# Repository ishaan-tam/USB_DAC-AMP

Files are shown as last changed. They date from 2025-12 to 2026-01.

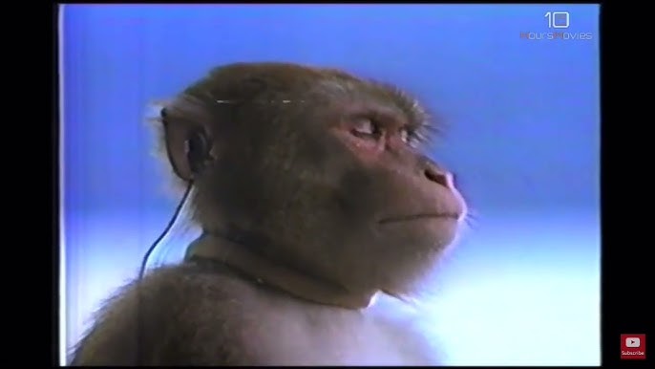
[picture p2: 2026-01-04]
Artwork/Monkey_listening_to_music.jpg

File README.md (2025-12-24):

# Pocket USB DAC Headphone Amp

# USB DAC + Baxandall Tone Control Headphone Amp  
**Checklist / Build Plan**

make sure that resistors are thin film, thich film resistors can introduce distortion
Chose electrolytic caps in the signal path as long as they are large enough, if chosing ceramic (sepecially in the signal path) chose type cog, otehrwise most ceramic caps will have piezoelectric effects and will introduce distortion 
bypass caps can be pretty much any type

For voltage ratings, useually go with double of what the expected DC voltage is
---

## Phase 0 — Lock the architecture
- [ ] Use **Phil’s USB headphone amplifier** as the base design
  - [ ] USB-C power + data
  - [ ] USB audio codec (PCM290x family)
  - [ ] DAC output buffer / reconstruction filter
  - [ ] Volume control stage
  - [ ] Output/current-drive stage to headphone jack
- [ ] Insert **TI Baxandall bass/treble tone control** as a line-level block
  - [ ] Signal flow:  
    **Phil DAC buffer → TI Baxandall tone → Phil volume → Phil output stage**
- [ ] Decide on **single master volume**
  - [ ] Use Phil’s volume control only
  - [ ] Bypass TI’s R1/R2 volume pots

---

## Phase 1 — KiCad schematic integration
- [ ] Create a **combined KiCad schematic**
  - [ ] Start from Phil’s schematic as the backbone
  - [ ] Add TI Baxandall tone block between Phil buffer output and Phil volume input
  - [ ] Keep TI input buffers initially (lower risk)
- [ ] **Bypass TI R1/R2 (volume pots)**
  - [ ] Remove R1/R2 from the TI tone schematic
  - [ ] Feed TI input buffer directly from the coupling cap
  - [ ] Add a DC bias path so the node does not float
  - [ ] (Optional) Add footprints / jumpers to re-enable pots if needed
- [ ] **Resolve virtual ground vs real ground**
  - [ ] Identify Phil’s analog reference / bias node (half-rail if single-supply)
  - [ ] Tie all TI “mid” nodes to Phil’s analog reference
  - [ ] Do NOT generate a separate TI virtual ground if Phil already provides one
- [ ] Perform a **sanity check**
  - [ ] Verify signal levels between stages
  - [ ] Ensure tone boost will not clip internal op-amps
  - [ ] Ensure compatibility with Phil’s volume stage input impedance

---

## Phase 2 — BOM & sourcing
- [ ] Create a **BOM from the combined schematic**
  - [ ] ICs (codec, op-amps, regulators)
  - [ ] Precision resistors where required
  - [ ] Capacitors (type + voltage rating)
  - [ ] Dual-gang pots for bass/treble
  - [ ] USB-C connector, headphone jack
  - [ ] Protection parts (ESD diodes, fuses, ferrites)
- [ ] Align BOM with **JLCPCB / LCSC availability**
  - [ ] Decide which ICs are hand-soldered
  - [ ] Mark which passives are PCBA-assembled
- [ ] Order parts
  - [ ] Order extras for iteration (pots, op-amps, passives)

---

## Phase 3 — Build & test
- [ ] Bring-up in stages
  - [ ] Test Phil’s base circuit (USB enumeration + clean audio)
  - [ ] Enable TI Baxandall tone block
  - [ ] Verify flat response at center
  - [ ] Verify bass/treble behavior
- [ ] Full system test
  - [ ] Verify volume control behavior
  - [ ] Test with headphones
  - [ ] Listen for noise, clipping, oscillation

---

## Phase 4 — Rev A refinement
- [ ] Adjust Baxandall network for **subtle** tone range if needed
- [ ] Improve decoupling/layout if noise or instability appears
- [ ] Finalize schematic and prepare for PCB layout / PCBA

A compact, USB-powered headphone amplifier built around a **class-compliant USB audio codec**, with an **analog signal path**, **physical volume control**, and room to add **Baxandall bass/treble tone shaping** in later revisions.

This project prioritizes:
- **Fun, hands-on analog audio**
- **Simple, driverless USB DAC operation**
- **Incremental development** (breadboard → PCB Rev A → Rev B tone control)

Not meant to be “audiophile-perfect,” but absolutely meant to be **good enough that I actually want to use it**.

---

## Project Status

- **Current phase:** Rev 0 — Breadboard prototype
- **Goal of Rev 0:**  
  - USB device enumerates as an audio output  
  - Audio plays cleanly through headphones  
  - Volume control works  
- **Future phases:**  
  - Rev A PCB (compact, USB-C, integrated headphone stage)  
  - Rev B (add Baxandall bass/treble tone control)

---

## High-Level Architecture

USB-C
│
├─ USB 2.0 D+/D−
│
PCM2906C USB Audio Codec
│
├─ DAC L/R (line-level)
│
Buffer + Reconstruction Filter
│
(Rev B) Baxandall Tone Control (Bass / Treble)
│
Volume Control
│
Headphone Output Stage
│
3.5 mm Headphone Jack

---

## Key Design Decisions

### USB Audio Codec
- **TI PCM2906C**
  - USB Audio Class 1 (driverless)
  - Plug-and-play on **Windows, macOS, Linux**
  - Likely works on **USB-C iPhones** (with power constraints)
  - Chosen over older PCM2900 due to **availability / active status**

S/PDIF pins are **not used** in this project.

---

### Power Strategy
- **Rev 0 (breadboard):**  
  - USB 5 V only  
  - No boost converter  
- **Rev A (PCB):**  
  - USB 5 V → boost → clean analog rail (12–15 V)  
  - Boost is for **headroom**, not “audio amplification”

---

### Analog Audio Philosophy
- Keep the **DAC isolated** from headphone loads
- Use **buffers** and **volume control** before the output stage
- Tone control is **optional and playful**, not surgical EQ
- If “serious EQ” is needed → do it digitally in software

---

### Tone Control Plan
- **Baxandall bass/treble** (2 knobs)
  - Musical, forgiving
  - Simple, stable, well-understood
- Will be added in **Rev B**
- Rev A PCB should reserve insertion points for it

---

## Breadboard Prototype (Rev 0)

### What Rev 0 Includes
- PCM2906C wired per TI **Typical Application Circuit**
- 12 MHz crystal + required decoupling
- USB-C input (USB 2.0 only)
- Line-level L/R output
- External headphone amp module **or** simple buffer + volume pot
- Goal: **“I hear sound and can control volume”**

### What Rev 0 Intentionally Avoids
- Boost converters
- Parallel op-amps
- Tone controls
- EMI optimization
- Fancy layouts

Rev 0 is about **function, not polish**.

---

## Headphone Output (Rev 0 Approach)

For breadboarding, the headphone stage is intentionally simplified:

### Options
1. **External headphone amp module**
   - Accepts line-level L/R
   - Powered from 5 V
   - Drives headphones safely
2. **DIY buffer + volume + output stage**
   - Unity-gain buffer
   - Passive volume pot
   - Headphone-capable driver

Modules are preferred for Rev 0 to avoid stability issues on a breadboard.

---

## Compatibility Expectations

- **Windows:** ✅ Plug-and-play
- **macOS / Linux:** ✅ Plug-and-play
- **USB-C iPhone:** ⚠️ Likely works, power-dependent
- **Lightning iPhone:** ⚠️ Requires camera adapter

---

## Repository Structure

pocket-usb-dac-amp/
├─ README.md
├─ docs/
│ ├─ requirements.md
│ ├─ architecture.md
│ ├─ bringup-notes.md
│ └─ images/
├─ hardware/
│ ├─ rev0_breadboard/
│ │ ├─ wiring/
│ │ └─ bom/
│ │ └─ bom_rev0.xlsx
│ ├─ revA_pcb/
│ │ ├─ kicad/
│ │ ├─ outputs/
│ │ └─ bom/
│ └─ revB_tonecontrol/
├─ tools/
│ └─ bom/
└─ CHANGELOG.md

---

## BOM Management

- BOMs are maintained in **Excel**
- Each revision has its own BOM:
  - `bom_rev0.xlsx`
  - `bom_revA.xlsx`
- BOM includes:
  - Manufacturer + MPN
  - Supplier + SKU
  - Unit cost
  - Alternates
  - Notes (DNP, experimental, etc.)

KiCad-exported CSVs are treated as **derived artifacts**, not the source of truth.

---

## Development Philosophy

- Build **one working version at a time**
- Breadboard first, PCB later
- Prefer **known-good reference circuits**
- Avoid “clever” designs that increase debug time
- Leave room for iteration and learning

---

## Non-Goals (Important)

- Not chasing ultra-low THD numbers
- Not competing with commercial DACs
- Not building a DSP playground
- Not optimizing for mass production

This is a **learning + enjoyment project**, not a product launch.

---

## Next Immediate Steps

1. Finish Rev 0 breadboard wiring
2. Confirm USB enumeration + audio playback
3. Document bring-up issues and fixes
4. Decide:
   - integrated output stage vs module
5. Begin Rev A schematic capture

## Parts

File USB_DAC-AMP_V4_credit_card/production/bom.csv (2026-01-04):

Designator | Footprint | Quantity | Value | LCSC Part #
C1, C11, C14, C19, C2, C20, C21, C23 | 0603 | 8 | 1u | C1592
C10, C12, C13, C15, C16, C28, C31, C4, C40, C43, C9 | 0603 | 11 | 30p | C1658
C17, C18, C22, C3, C5, C6, C8 | 0603 | 7 | 10u | C1035
C24, C25, C33, C34, C36, C37, C45 | 0603 | 7 | 100n | C1590
C26, C38 | CP_Elec_10x10.5 | 2 | 1000u | C3359
C27, C29, C32, C35, C39, C41, C44, C7 | CP_Elec_6.3x7.7 | 8 | 100u | C3339
C30, C42 | 0603 | 2 | 2.2n | C1028
D1, D5 | D_SMA | 2 | SS14 | C2480
D2 | 0603 | 1 | LED | C84265
D3, D4, D6, D7 | 0603 | 4 | D_TVS | C316055
F1 | 0603 | 1 | Polyfuse - 750mA | C20787
FB1, FB2, FB3, FB4, FB5 | 0603 | 5 | 120R | C12391
J1 | USB_C_Receptacle_GCT_USB4105-xx-A_16P_TopMnt_Horizontal | 1 | USB_C_Receptacle | C5184243
J2 | SJ-3524-SMT | 1 | SJ-3524-SMT
L1 | 0805 | 1 | 10u | C223269
R1 | 0603 | 1 | 20 | C136969
R10, R2 | 0603 | 2 | 1M | C326730
R11, R12, R24, R35, R5, R6 | 0603 | 6 | 5.1K | C122969
R13, R14, R15, R20, R25, R28, R29, R30, R32, R36, R39, R8 | 0603 | 12 | 22K | C217885
R16, R22, R23, R26, R33, R34, R37, R4, R40 | 0603 | 9 | 1.5K | C193681
R17, R18 | 0603 | 2 | 22 | C217888
R19, R27, R31, R38, R9 | 0603 | 5 | 1 | C412388
R21 | TRIM_PTN092-H20115K1A | 1 | PTN092-H20115K1A
R3 | 0603 | 1 | 240K | C217899
R7 | 0603 | 1 | 84.5K | C705797
TP1 | TestPoint_Pad_1.0x1.0mm | 1 | +5V
TP11 | TestPoint_Pad_1.0x1.0mm | 1 | buffer2_r
TP12 | TestPoint_Pad_1.0x1.0mm | 1 | buffer2_l
TP13 | TestPoint_Pad_1.0x1.0mm | 1 | in_l
TP14 | TestPoint_Pad_1.0x1.0mm | 1 | in_r
TP15 | TestPoint_Pad_1.0x1.0mm | 1 | buffer1_l
TP16 | TestPoint_Pad_1.0x1.0mm | 1 | buffer1_r
TP2 | TestPoint_Pad_1.0x1.0mm | 1 | +16V
TP3 | TestPoint_Pad_1.0x1.0mm | 1 | +15VA
TP4 | TestPoint_Pad_1.0x1.0mm | 1 | +3.7V
TP5 | TestPoint_Pad_1.0x1.0mm | 1 | U1_VCCI
TP6 | TestPoint_Pad_1.0x1.0mm | 1 | VBL
TP7 | TestPoint_Pad_1.0x1.0mm | 1 | VREF
TP8 | TestPoint_Pad_1.0x1.0mm | 1 | VBR
U1 | SOT-23-5 | 1 | TPS61040DBV | C7722
U10, U11, U5, U6, U7, U8, U9 | SOIC-8_3.9x4.9mm_P1.27mm | 7 | NE5532 | C7426
U2, U3 | SOT-23-5 | 2 | SPX3819M5-L | C9056
U4 | SSOP-28_5.3x10.2mm_P0.65mm | 1 | PCM2900C | C180425
Y1 | Crystal_SMD_3225-4Pin_3.2x2.5mm | 1 | 12 MHz Crystal | C9002

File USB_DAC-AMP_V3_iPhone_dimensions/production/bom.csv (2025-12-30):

Designator | Footprint | Quantity | Value | LCSC Part #
C1, C10, C11, C12, C13, C19, C9 | 0603 | 7 | 10u
C14, C15, C35, C45 | CP_EIA-7343-43_Kemet-X_HandSolder | 4 | 1000u
C16, C17, C18, C20, C21, C22, C7, C8 | 0603 | 8 | 1u
C2, C23, C24, C3, C33, C36, C4, C43, C46, C5, C6 | 0603 | 11 | 30p
C25, C27, C30, C31, C40, C41 | CP_EIA-7343-43_Kemet-X_HandSolder | 6 | 100u
C26, C28, C32, C34, C38, C42, C44, C47 | 0603 | 8 | 100n
C29, C39 | 0603 | 2 | 2.2n
C37 | CP_EIA-7343-15_Kemet-W | 1 | 100u
D1, D6, D7 | 0603 | 3 | D_TVS
D2 | 0603 | 1 | 0603ESDA-18N
D3 | 0603 | 1 | LED
D4, D5 | D_SMA | 2 | SS14
F1 | 0603 | 1 | Polyfuse - 750mA
FB1, FB2, FB3, FB4, FB5 | 0603 | 5 | 120R
J1 | USB_C_Receptacle_GCT_USB4105-xx-A_16P_TopMnt_Horizontal | 1 | USB_C_Receptacle
J2 | SJ-3524-SMT | 1 | SJ-3524-SMT
L1 | 0805 | 1 | 10u
R1, R2, R30, R40 | 0603 | 4 | 5.1K
R10 | 0603 | 1 | 240K
R11, R23, R24, R25, R29, R34, R39, R7, R8, R9 | 0603 | 10 | 22K
R12 | 0603 | 1 | 20
R13, R16, R20, R21, R26, R27, R28, R33, R35, R36, R38, R43 | 0603 | 12 | 1.5K
R14, R15 | 0603 | 2 | 22
R17, R31, R32, R41, R42 | 0603 | 5 | 1
R22, R5 | 0603 | 2 | 1M
R3 | TRIM_PTN092-H20115K1A | 1 | PTN092-H20115K1A
R6 | 0603 | 1 | 84.5K
TP1 | TestPoint_Pad_1.0x1.0mm | 1 | +5V
TP2 | TestPoint_Pad_1.0x1.0mm | 1 | +16V
TP3 | TestPoint_Pad_1.0x1.0mm | 1 | +3.7V
TP4 | TestPoint_Pad_1.0x1.0mm | 1 | +15VA
TP5 | TestPoint_Pad_1.0x1.0mm | 1 | VREF
TP6 | TestPoint_Pad_1.0x1.0mm | 1 | U1_VCCI
TP7 | TestPoint_Pad_1.0x1.0mm | 1 | VBL
TP8 | TestPoint_Pad_1.0x1.0mm | 1 | VBR
U1 | SSOP-28_5.3x10.2mm_P0.65mm | 1 | PCM2900C
U10, U11, U5, U6, U7, U8, U9 | SOIC-8_5.3x5.3mm_P1.27mm | 7 | NE5532
U2 | SOT-23-5 | 1 | TPS61040DBV
U3, U4 | SOT-23-5 | 2 | SPX3819M5-L
Y3 | Crystal_SMD_3225-4Pin_3.2x2.5mm | 1 | 12 MHz Crystal

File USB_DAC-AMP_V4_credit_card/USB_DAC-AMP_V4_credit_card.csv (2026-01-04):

Value | LCSC | Reference | Footprint | Qty
1u | C1592 | C1,C2,C11,C14,C19,C20,C21,C23 | Capacitor_SMD:C_0603_1608Metric | 8
10u | C1035 | C3,C5,C6,C8,C17,C18,C22 | Capacitor_SMD:C_0603_1608Metric | 7
30p | C1658 | C4,C9,C10,C12,C13,C15,C16,C28,C31,C40,C43 | Capacitor_SMD:C_0603_1608Metric | 11
100n | C1590 | C24,C25,C33,C34,C36,C37,C45 | Capacitor_SMD:C_0603_1608Metric | 7
2.2n | C1028 | C30,C42 | Capacitor_SMD:C_0603_1608Metric | 2
1000u | C3359 | C26,C38 | Capacitor_SMD:CP_Elec_10x10.5 | 2
100u | C3339 | C7,C27,C29,C32,C35,C39,C41,C44 | Capacitor_SMD:CP_Elec_6.3x7.7 | 8
USB_C_Receptacle | C5184243 | J1 | Connector_USB:USB_C_Receptacle_GCT_USB4105-xx-A_16P_TopMnt_Horizontal | 1
12 MHz Crystal | C9002 | Y1 | Crystal:Crystal_SMD_3225-4Pin_3.2x2.5mm | 1
D_TVS | C316055 | D3,D4,D6,D7 | Diode_SMD:D_0603_1608Metric | 4
SS14 | C2480 | D1,D5 | Diode_SMD:D_SMA | 2
Polyfuse - 750mA | C20787 | F1 | Fuse:Fuse_0603_1608Metric | 1
SJ-3524-SMT |  | J2 | Imported_footprints:SJ-3524-SMT | 1
PTN092-H20115K1A |  | R21 | Imported_footprints:TRIM_PTN092-H20115K1A | 1
10u | C223269 | L1 | Inductor_SMD:L_0805_2012Metric | 1
LED | C84265 | D2 | LED_SMD:LED_0603_1608Metric | 1
MountingHole |  | H1,H2,H3,H4 | MountingHole:MountingHole_3.5mm | 4
NE5532 | C7426 | U5,U6,U7,U8,U9,U10,U11 | Package_SO:SOIC-8_3.9x4.9mm_P1.27mm | 7
PCM2900C | C180425 | U4 | Package_SO:SSOP-28_5.3x10.2mm_P0.65mm | 1
TPS61040DBV | C7722 | U1 | Package_TO_SOT_SMD:SOT-23-5 | 1
SPX3819M5-L | C9056 | U2,U3 | Package_TO_SOT_SMD:SOT-23-5 | 2
120R | C12391 | FB1,FB2,FB3,FB4,FB5 | Resistor_SMD:R_0603_1608Metric | 5
20 | C136969 | R1 | Resistor_SMD:R_0603_1608Metric | 1
1M | C326730 | R2,R10 | Resistor_SMD:R_0603_1608Metric | 2
240K | C217899 | R3 | Resistor_SMD:R_0603_1608Metric | 1
1.5K | C193681 | R4,R16,R22,R23,R26,R33,R34,R37,R40 | Resistor_SMD:R_0603_1608Metric | 9
5.1K | C122969 | R5,R6,R11,R12,R24,R35 | Resistor_SMD:R_0603_1608Metric | 6
84.5K | C705797 | R7 | Resistor_SMD:R_0603_1608Metric | 1
22K | C217885 | R8,R13,R14,R15,R20,R25,R28,R29,R30,R32,R36,R39 | Resistor_SMD:R_0603_1608Metric | 12
1 | C412388 | R9,R19,R27,R31,R38 | Resistor_SMD:R_0603_1608Metric | 5
22 | C217888 | R17,R18 | Resistor_SMD:R_0603_1608Metric | 2
+5V |  | TP1 | TestPoint:TestPoint_Pad_1.0x1.0mm | 1
+16V |  | TP2 | TestPoint:TestPoint_Pad_1.0x1.0mm | 1
+15VA |  | TP3 | TestPoint:TestPoint_Pad_1.0x1.0mm | 1
+3.7V |  | TP4 | TestPoint:TestPoint_Pad_1.0x1.0mm | 1
U1_VCCI |  | TP5 | TestPoint:TestPoint_Pad_1.0x1.0mm | 1
VBL |  | TP6 | TestPoint:TestPoint_Pad_1.0x1.0mm | 1
VREF |  | TP7 | TestPoint:TestPoint_Pad_1.0x1.0mm | 1
VBR |  | TP8 | TestPoint:TestPoint_Pad_1.0x1.0mm | 1
buffer2_r |  | TP11 | TestPoint:TestPoint_Pad_1.0x1.0mm | 1
buffer2_l |  | TP12 | TestPoint:TestPoint_Pad_1.0x1.0mm | 1
in_l |  | TP13 | TestPoint:TestPoint_Pad_1.0x1.0mm | 1
in_r |  | TP14 | TestPoint:TestPoint_Pad_1.0x1.0mm | 1
buffer1_l |  | TP15 | TestPoint:TestPoint_Pad_1.0x1.0mm | 1
buffer1_r |  | TP16 | TestPoint:TestPoint_Pad_1.0x1.0mm | 1

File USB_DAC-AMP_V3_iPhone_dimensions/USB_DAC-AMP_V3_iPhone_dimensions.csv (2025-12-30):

Value | LCSC | Reference | Footprint | Qty
10u | C1035 | C1,C9,C10,C11,C12,C13,C19 | Capacitor_SMD:C_0603_1608Metric_Pad1.08x0.95mm_HandSolder | 7
30p | C1658 | C2,C3,C4,C5,C6,C23,C24,C33,C36,C43,C46 | Capacitor_SMD:C_0603_1608Metric_Pad1.08x0.95mm_HandSolder | 11
1u | C1592 | C7,C8,C16,C17,C18,C20,C21,C22 | Capacitor_SMD:C_0603_1608Metric_Pad1.08x0.95mm_HandSolder | 8
1000u | C696799 | C14,C15,C35,C45 | Capacitor_Tantalum_SMD:CP_EIA-7343-43_Kemet-X_HandSolder | 4
100u | C132558 | C25,C27,C30,C31,C40,C41 | Capacitor_Tantalum_SMD:CP_EIA-7343-43_Kemet-X_HandSolder | 6
100n | C1590 | C26,C28,C32,C34,C38,C42,C44,C47 | Capacitor_SMD:C_0603_1608Metric_Pad1.08x0.95mm_HandSolder | 8
2.2n | C1028 | C29,C39 | Capacitor_SMD:C_0603_1608Metric_Pad1.08x0.95mm_HandSolder | 2
100u | C1002 | C37 | Capacitor_Tantalum_SMD:CP_EIA-7343-15_Kemet-W | 1
D_TVS | C316055 | D1,D2,D6,D7 | Diode_SMD:D_0603_1608Metric_Pad1.05x0.95mm_HandSolder | 4
LED | C2288 | D3 | LED_SMD:LED_0603_1608Metric_Pad1.05x0.95mm_HandSolder | 1
SS14 | C2480 | D4,D5 | Diode_SMD:D_SMA | 2
Polyfuse - 750mA | C20787 | F1 | Fuse:Fuse_0603_1608Metric_Pad1.05x0.95mm_HandSolder | 1
120R | C12391 | FB1,FB2,FB3,FB4,FB5 | Resistor_SMD:R_0603_1608Metric_Pad0.98x0.95mm_HandSolder | 5
MountingHole |  | H1,H2,H3,H4 | MountingHole:MountingHole_3.5mm | 4
USB_C_Receptacle | C5184243 | J1 | Connector_USB:USB_C_Receptacle_GCT_USB4105-xx-A_16P_TopMnt_Horizontal | 1
SJ-3524-SMT |  | J2 | Imported_footprints:SJ-3524-SMT | 1
10u | C223269 | L1 | Inductor_SMD:L_0805_2012Metric_Pad1.05x1.20mm_HandSolder | 1
5.1K | C122969 | R1,R2,R30,R40 | Resistor_SMD:R_0603_1608Metric_Pad0.98x0.95mm_HandSolder | 4
PTN092-H20115K1A |  | R3 | Imported_footprints:TRIM_PTN092-H20115K1A | 1
1M | C705797 | R5,R22 | Resistor_SMD:R_0603_1608Metric_Pad0.98x0.95mm_HandSolder | 2
84.5K |  | R6 | Resistor_SMD:R_0603_1608Metric_Pad0.98x0.95mm_HandSolder | 1
22K |  | R7,R8,R9,R11,R23,R24,R25,R29,R34,R39 | Resistor_SMD:R_0603_1608Metric_Pad0.98x0.95mm_HandSolder | 10
240K |  | R10 | Resistor_SMD:R_0603_1608Metric_Pad0.98x0.95mm_HandSolder | 1
20 |  | R12 | Resistor_SMD:R_0603_1608Metric_Pad0.98x0.95mm_HandSolder | 1
1.5K |  | R13,R16,R26,R27,R28,R33,R35,R36,R38,R43 | Resistor_SMD:R_0603_1608Metric_Pad0.98x0.95mm_HandSolder | 10
22 |  | R14,R15 | Resistor_SMD:R_0603_1608Metric_Pad0.98x0.95mm_HandSolder | 2
1 |  | R17,R31,R32,R41,R42 | Resistor_SMD:R_0603_1608Metric_Pad0.98x0.95mm_HandSolder | 5
1.5k |  | R20,R21 | Resistor_SMD:R_0603_1608Metric_Pad0.98x0.95mm_HandSolder | 2
+5V |  | TP1 | TestPoint:TestPoint_Pad_1.0x1.0mm | 1
+16V |  | TP2 | TestPoint:TestPoint_Pad_1.0x1.0mm | 1
+3.7V |  | TP3 | TestPoint:TestPoint_Pad_1.0x1.0mm | 1
+15VA |  | TP4 | TestPoint:TestPoint_Pad_1.0x1.0mm | 1
VREF |  | TP5 | TestPoint:TestPoint_Pad_1.0x1.0mm | 1
U1_VCCI |  | TP6 | TestPoint:TestPoint_Pad_1.0x1.0mm | 1
VBL |  | TP7 | TestPoint:TestPoint_Pad_1.0x1.0mm | 1
VBR |  | TP8 | TestPoint:TestPoint_Pad_1.0x1.0mm | 1
PCM2900C | C180425 | U1 | Package_SO:SSOP-28_5.3x10.2mm_P0.65mm | 1
TPS61040DBV | C7722 | U2 | Package_TO_SOT_SMD:SOT-23-5 | 1
SPX3819M5-L | C9056 | U3,U4 | Package_TO_SOT_SMD:SOT-23-5 | 2
NE5532 | C7426 | U5,U6,U7,U8,U9,U10,U11 | Package_SO:SOIC-8_5.3x5.3mm_P1.27mm | 7
12 MHz Crystal | C9002 | Y3 | Crystal:Crystal_SMD_3225-4Pin_3.2x2.5mm | 1

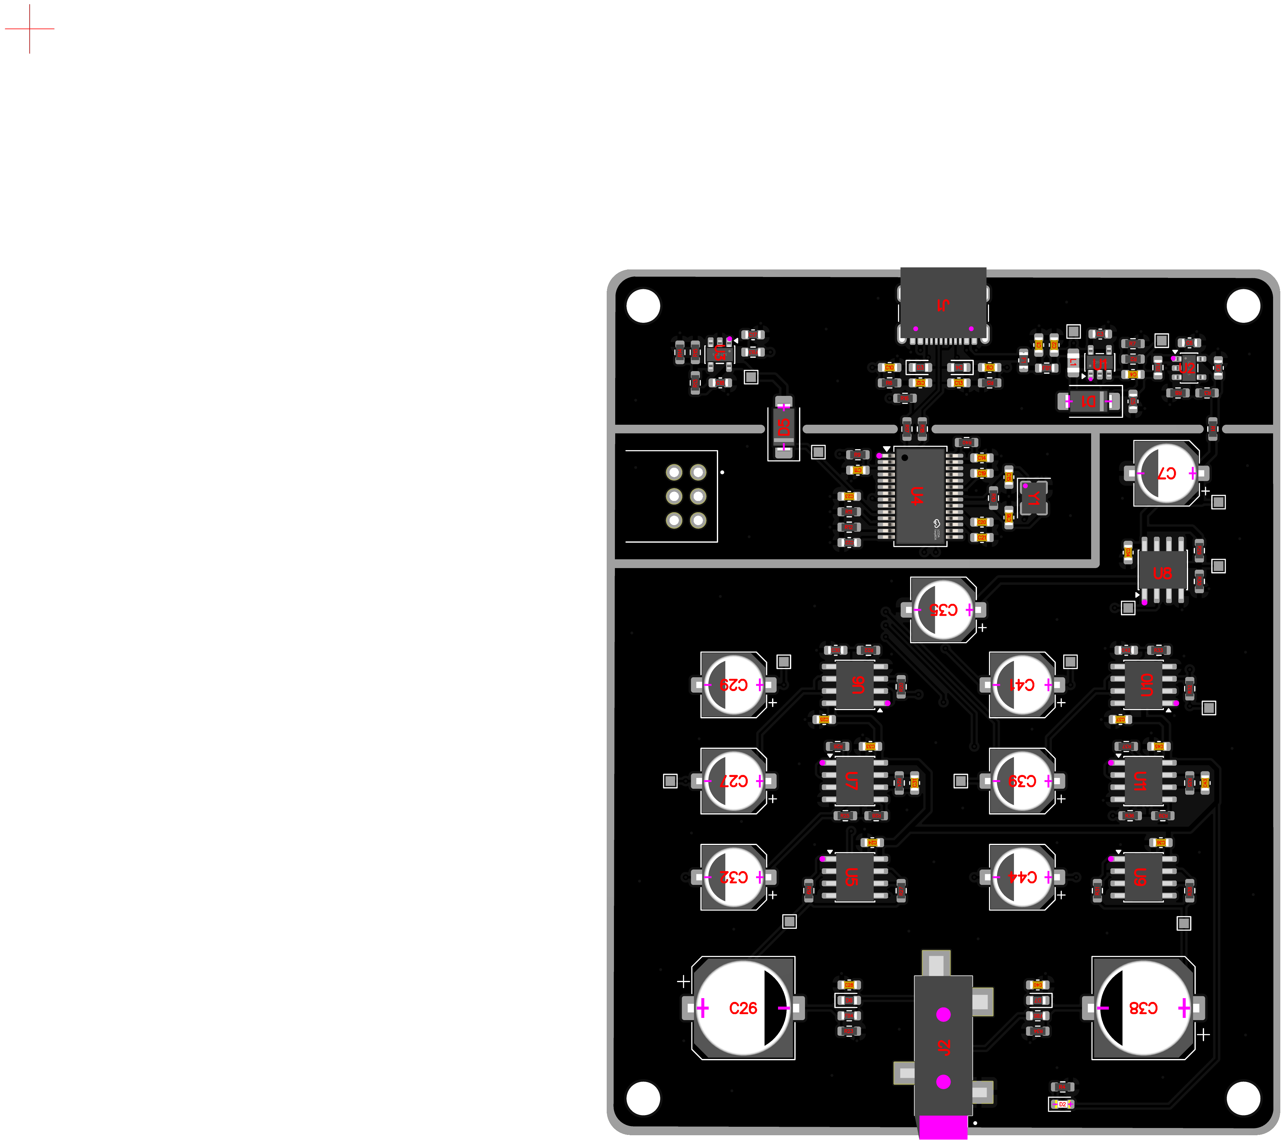
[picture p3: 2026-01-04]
JLC_V1_order_submission.png

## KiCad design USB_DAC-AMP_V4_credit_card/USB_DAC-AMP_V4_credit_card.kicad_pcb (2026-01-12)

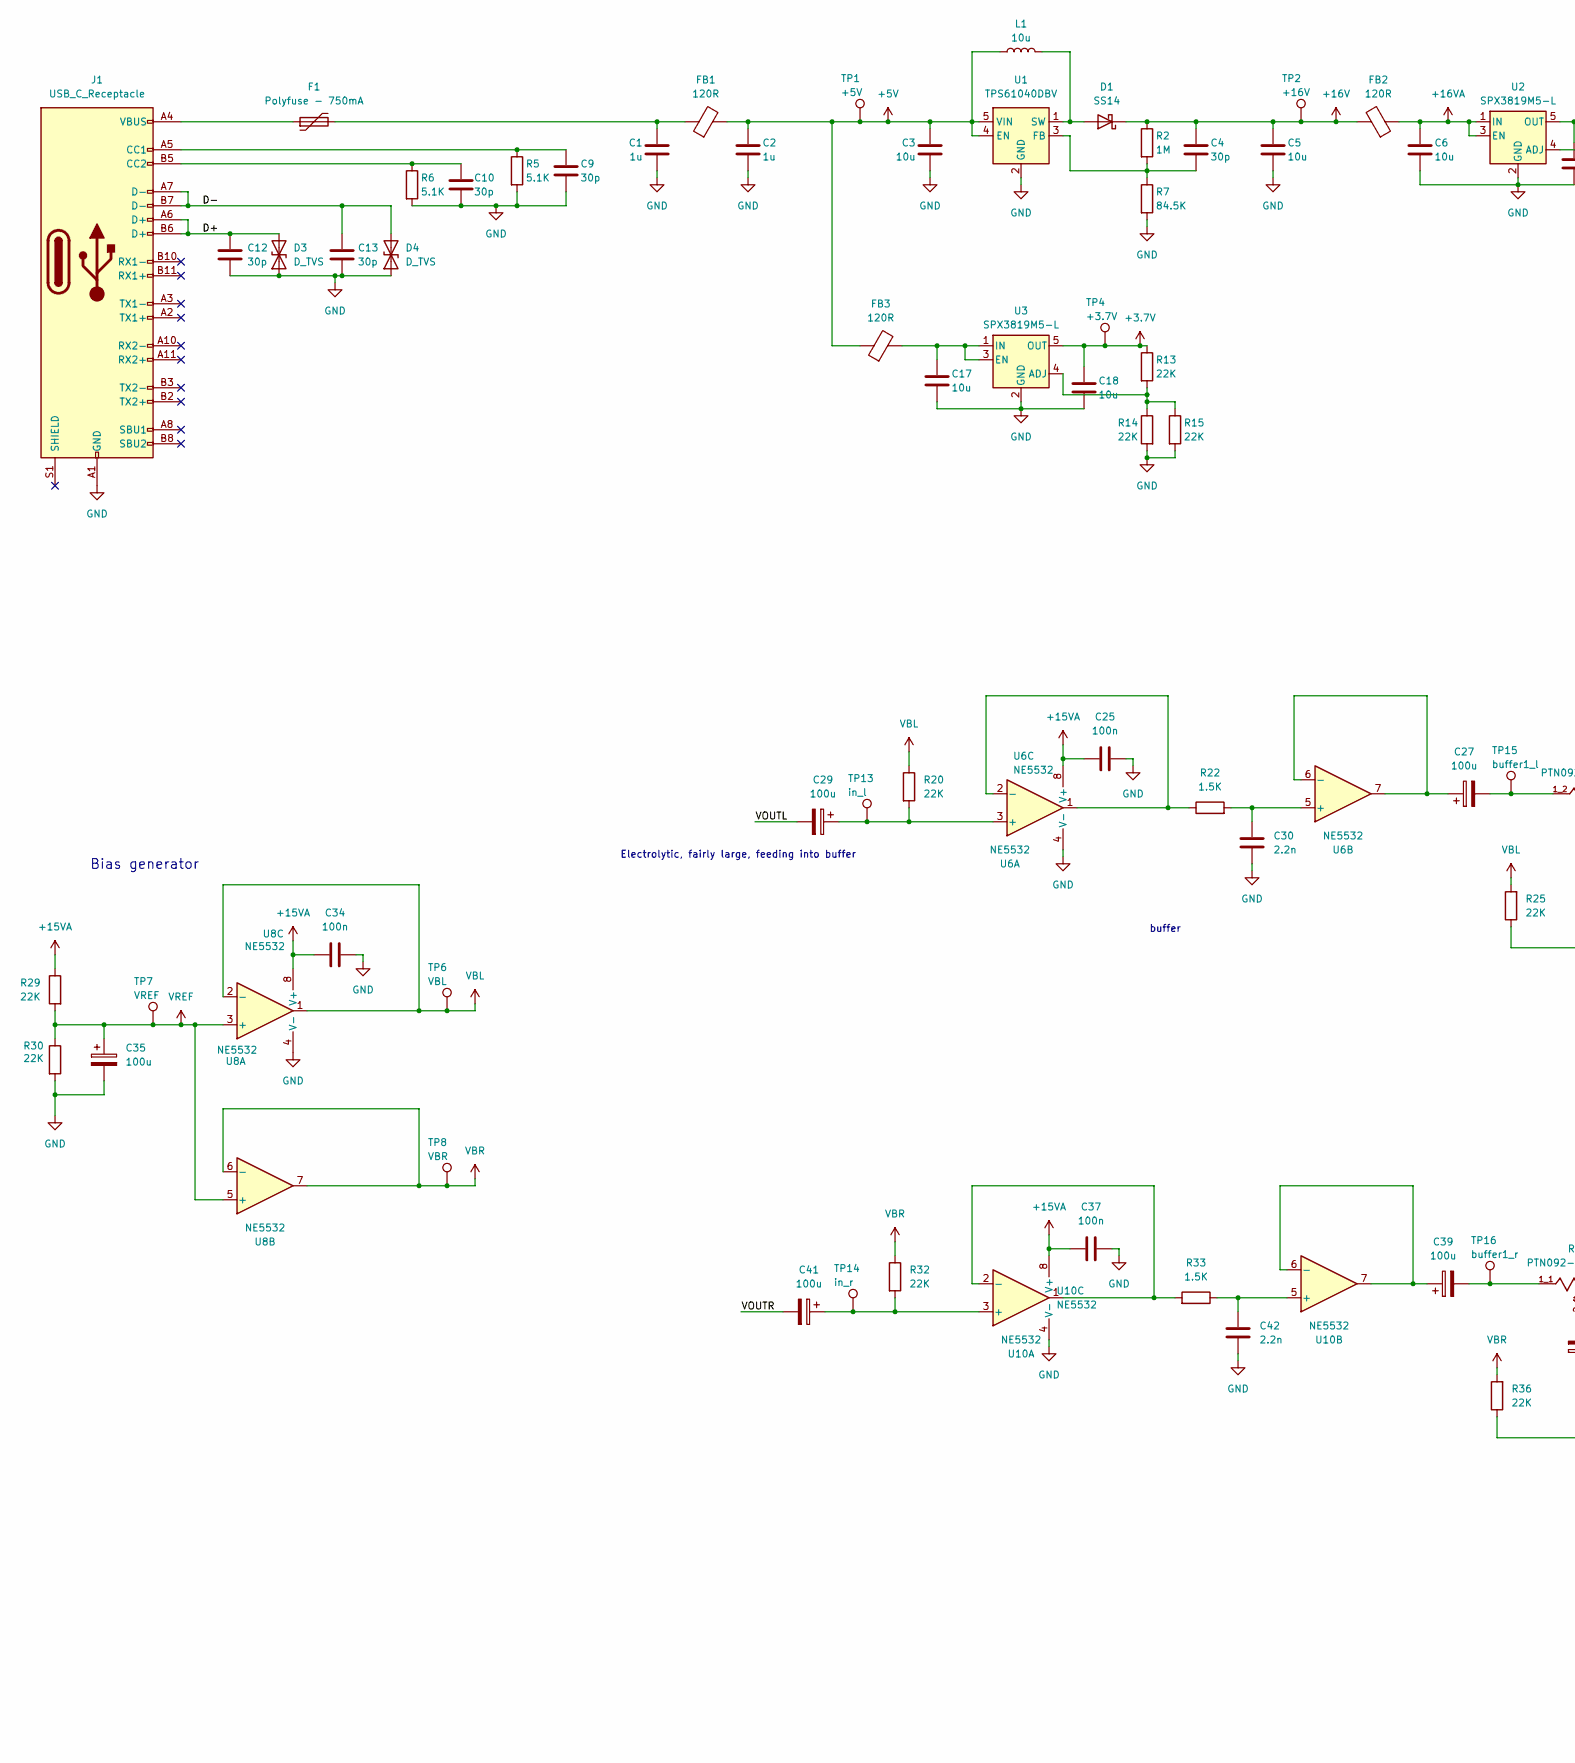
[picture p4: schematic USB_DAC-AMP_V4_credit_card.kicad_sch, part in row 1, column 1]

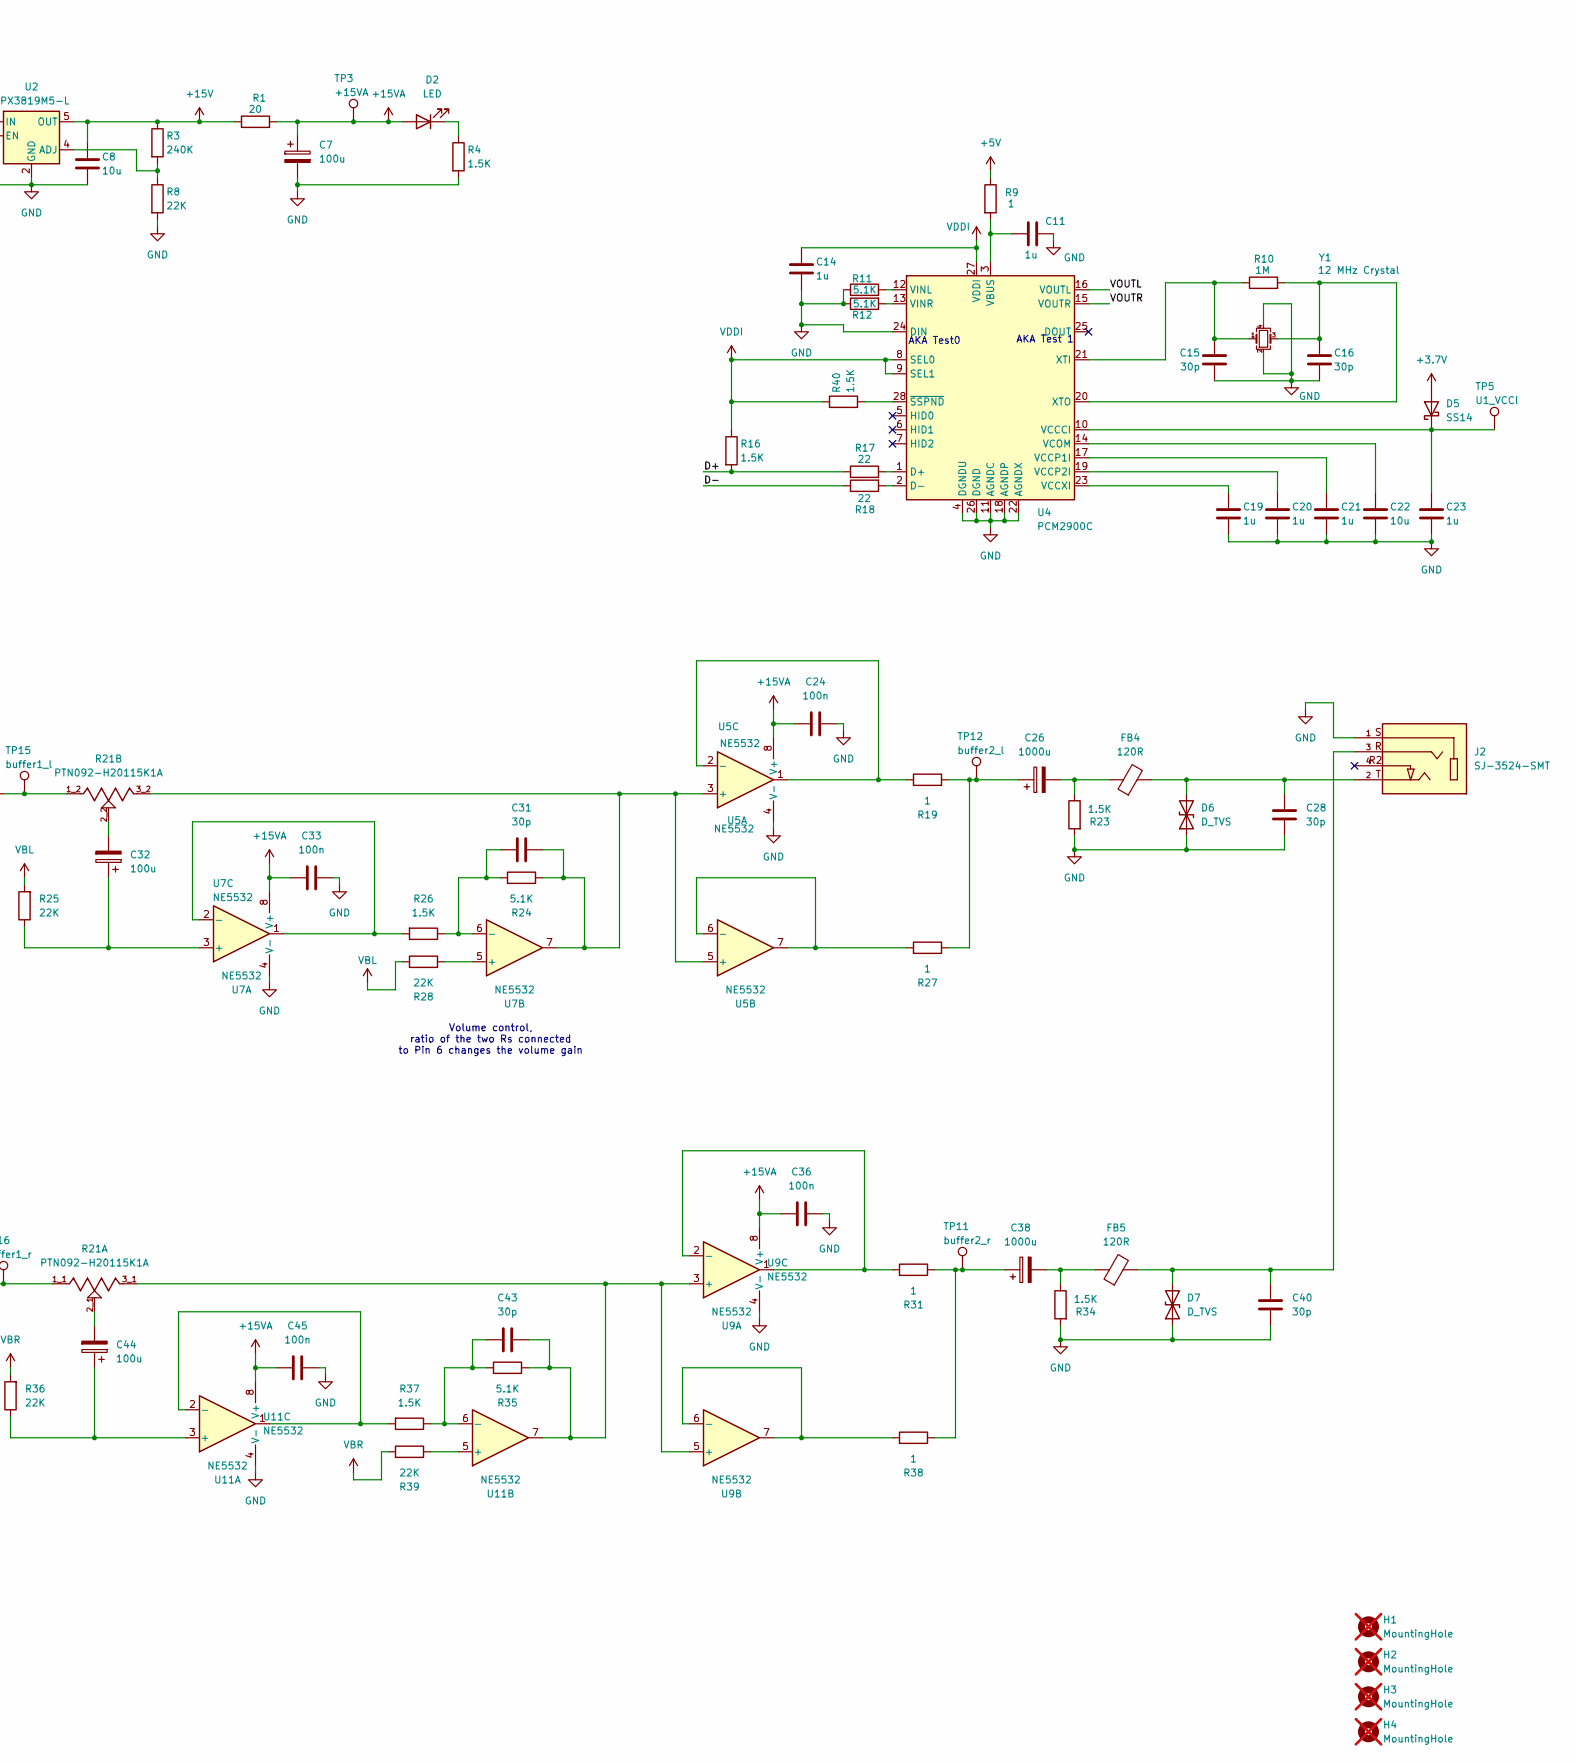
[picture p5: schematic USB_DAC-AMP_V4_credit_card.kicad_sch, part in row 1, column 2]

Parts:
C1, C2, C11, C14, C19, C20, C21, C23: 1u; C_0603_1608Metric; LCSC C1592
C3, C5, C6, C8, C17, C18, C22: 10u; C_0603_1608Metric; LCSC C1035
C4, C9, C10, C12, C13, C15, C16, C28, C31, C40, C43: 30p; C_0603_1608Metric; LCSC C1658
C7, C27, C29, C32, C35, C39, C41, C44: 100u; CP_Elec_6.3x7.7; LCSC C3339
C24, C25, C33, C34, C36, C37, C45: 100n; C_0603_1608Metric; LCSC C1590
C26, C38: 1000u; CP_Elec_10x10.5; LCSC C3359
C30, C42: 2.2n; C_0603_1608Metric; LCSC C1028
D1, D5: SS14; D_SMA; LCSC C2480
D2: LED; LED_0603_1608Metric; LCSC C84265
D3, D4, D6, D7: D_TVS; D_0603_1608Metric; LCSC C316055
F1: Polyfuse - 750mA; Fuse_0603_1608Metric; LCSC C20787
FB1, FB2, FB3, FB4, FB5: 120R; R_0603_1608Metric; LCSC C12391
H1, H2, H3, H4: MountingHole; MountingHole_3.5mm; not fitted
J1: USB_C_Receptacle; USB_C_Receptacle_GCT_USB4105-xx-A_16P_TopMnt_Horizontal; LCSC C5184243
J2: SJ-3524-SMT; PARTREV 1.03; DigiKey_Part_Number CP-3524SJCT-ND
L1: 10u; L_0805_2012Metric; LCSC C223269
R1: 20; R_0603_1608Metric; LCSC C136969
R2, R10: 1M; R_0603_1608Metric; LCSC C326730
R3: 240K; R_0603_1608Metric; LCSC C217899
R4, R16, R22, R23, R26, R33, R34, R37, R40: 1.5K; R_0603_1608Metric; LCSC C193681
R5, R6, R11, R12, R24, R35: 5.1K; R_0603_1608Metric; LCSC C122969
R7: 84.5K; R_0603_1608Metric; LCSC C705797
R8, R13, R14, R15, R20, R25, R28, R29, R30, R32, R36, R39: 22K; R_0603_1608Metric; LCSC C217885
R9, R19, R27, R31, R38: 1; R_0603_1608Metric; LCSC C412388
R17, R18: 22; R_0603_1608Metric; LCSC C217888
R21: PTN092-H20115K1A; TRIM_PTN092-H20115K1A; PARTREV 1.01; DigiKey_Part_Number 2223-PTN092-H20115K1A-ND
TP1: +5V; TestPoint_Pad_1.0x1.0mm
TP2: +16V; TestPoint_Pad_1.0x1.0mm
TP3: +15VA; TestPoint_Pad_1.0x1.0mm
TP4: +3.7V; TestPoint_Pad_1.0x1.0mm
TP5: U1_VCCI; TestPoint_Pad_1.0x1.0mm
TP6: VBL; TestPoint_Pad_1.0x1.0mm
TP7: VREF; TestPoint_Pad_1.0x1.0mm
TP8: VBR; TestPoint_Pad_1.0x1.0mm
TP11: buffer2_r; TestPoint_Pad_1.0x1.0mm
TP12: buffer2_l; TestPoint_Pad_1.0x1.0mm
TP13: in_l; TestPoint_Pad_1.0x1.0mm
TP14: in_r; TestPoint_Pad_1.0x1.0mm
TP15: buffer1_l; TestPoint_Pad_1.0x1.0mm
TP16: buffer1_r; TestPoint_Pad_1.0x1.0mm
U1: TPS61040DBV; SOT-23-5; LCSC C7722
U2, U3: SPX3819M5-L; SOT-23-5; LCSC C9056
U4: PCM2900C; SSOP-28_5.3x10.2mm_P0.65mm; LCSC C180425
U5, U6, U7, U8, U9, U10, U11: NE5532; SOIC-8_3.9x4.9mm_P1.27mm; LCSC C7426
Y1: 12 MHz Crystal; Crystal_SMD_3225-4Pin_3.2x2.5mm; LCSC C9002

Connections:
+3.7V: C18.1, D5.2 (A), R13.1, TP4.1, U3.5 (OUT)
+5V: C2.1, C3.1, FB1.2, FB3.1, L1.1, R9.1, TP1.1, U1.4 (EN), U1.5 (VIN)
+15V: C8.1, R1.1, R3.1, U2.5 (OUT)
+15VA: C7.1, C24.1, C25.1, C33.1, C34.1, C36.1, C37.1, C45.1, D2.2 (A), R1.2, R29.1, TP3.1, U5.8 (V+), U6.8 (V+), U7.8 (V+), U8.8 (V+), U9.8 (V+), U10.8 (V+), U11.8 (V+)
+16V: C4.1, C5.1, D1.1 (K), FB2.2, R2.1, TP2.1
+16VA: C6.1, FB2.1, U2.1 (IN), U2.3 (EN)
/D+: C12.1, D3.2 (A2), J1.A6 (D+), J1.B6 (D+), R16.2, R17.1
/D-: C13.1, D4.2 (A2), J1.A7 (D-), J1.B7 (D-), R18.1
/VOUTL: C29.2, U4.16 (VOUTL)
/VOUTR: C41.2, U4.15 (VOUTR)
GND: C1.2, C2.2, C3.2, C5.2, C6.2, C7.2, C8.2, C9.2, C10.2, C11.2, C12.2, C13.2, C14.2, C15.2, C16.2, C17.2, C18.2, C19.2, C20.2, C21.2, C22.2, C23.2, C24.2, C25.2, C28.1, C30.1, C33.2, C34.2, C35.2, C36.2, C37.2, C40.1, C42.1, C45.2, D3.1 (A1), D4.1 (A1), D6.1 (A1), D7.1 (A1), J1.A1 (GND), J1.A12 (GND), J1.B1 (GND), J1.B12 (GND), J2.1, R4.2, R5.2, R6.2, R7.2, R8.2, R11.1, R12.1, R14.2, R15.2, R23.2, R30.2, R34.2, U1.2 (GND), U2.2 (GND), U3.2 (GND), U4.4 (DGNDU), U4.11 (AGNDC), U4.18 (AGNDP), U4.22 (AGNDX), U4.24 (DIN), U4.26 (DGND), U5.4 (V-), U6.4 (V-), U7.4 (V-), U8.4 (V-), U9.4 (V-), U10.4 (V-), U11.4 (V-), Y1.2, Y1.4
unnamed: C1.1, F1.2, FB1.1
unnamed: C26.1, R19.2, R27.1, TP12.1
unnamed: C26.2, FB4.1, R23.1
unnamed: C27.2, R21.1_2, TP15.1
unnamed: C32.2, R21.2_2
unnamed: C38.1, R31.1, R38.1, TP11.1
unnamed: C38.2, FB5.1, R34.1
unnamed: C39.2, R21.1_1, TP16.1
unnamed: C44.2, R21.2_1
unnamed: D1.2 (A), L1.2, U1.1 (SW)
unnamed: D2.1 (K), R4.1
unnamed: C23.1, D5.1 (K), TP5.1, U4.10 (VCCCI)
unnamed: C28.2, D6.2 (A2), FB4.2, J2.2
unnamed: C40.2, D7.2 (A2), FB5.2, J2.3
unnamed: F1.1, J1.A4 (VBUS), J1.A9 (VBUS), J1.B4 (VBUS), J1.B9 (VBUS)
unnamed: C9.1, J1.A5 (CC1), R5.1
unnamed: C10.1, J1.B5 (CC2), R6.1
unnamed: C4.2, R2.2, R7.1, U1.3 (FB)
unnamed: R3.2, R8.1, U2.4 (ADJ)
unnamed: R13.2, R14.1, R15.1, U3.4 (ADJ)
unnamed: C17.1, FB3.2, U3.1 (IN), U3.3 (EN)
unnamed: R17.2, U4.1 (D+)
unnamed: R18.2, U4.2 (D-)
unnamed: C11.1, R9.2, U4.3 (VBUS)
unnamed: C21.1, U4.17 (VCCP1I)
unnamed: C20.1, U4.19 (VCCP2I)
unnamed: C19.1, U4.23 (VCCXI)
unnamed: C22.1, U4.14 (VCOM)
unnamed: R11.2, U4.12 (VINL)
unnamed: R12.2, U4.13 (VINR)
unnamed: C15.1, R10.1, U4.21 (XTI), Y1.1
unnamed: C16.1, R10.2, U4.20 (XTO), Y1.3
unnamed: R40.2, U4.28 (~SSPND)
unnamed: C31.2, R21.3_2, R24.1, U5.3 (+), U5.5 (+), U7.7
unnamed: R19.1, U5.1, U5.2 (-)
unnamed: R27.2, U5.6 (-), U5.7
unnamed: C29.1, R20.2, TP13.1, U6.3 (+)
unnamed: R22.1, U6.1, U6.2 (-)
unnamed: C30.2, R22.2, U6.5 (+)
unnamed: C27.1, U6.6 (-), U6.7
unnamed: C32.1, R25.1, U7.3 (+)
unnamed: R26.2, U7.1, U7.2 (-)
unnamed: R28.1, U7.5 (+)
unnamed: C31.1, R24.2, R26.1, U7.6 (-)
unnamed: C43.2, R21.3_1, R35.1, U9.3 (+), U9.5 (+), U11.7
unnamed: R31.2, U9.1, U9.2 (-)
unnamed: R38.2, U9.6 (-), U9.7
unnamed: C41.1, R32.2, TP14.1, U10.3 (+)
unnamed: R33.2, U10.1, U10.2 (-)
unnamed: C42.2, R33.1, U10.5 (+)
unnamed: C39.1, U10.6 (-), U10.7
unnamed: C44.1, R36.1, U11.3 (+)
unnamed: R37.2, U11.1, U11.2 (-)
unnamed: R39.1, U11.5 (+)
unnamed: C43.1, R35.2, R37.1, U11.6 (-)
VBL: R20.1, R25.2, R28.2, TP6.1, U8.1, U8.2 (-)
VBR: R32.1, R36.2, R39.2, TP8.1, U8.6 (-), U8.7
VDDI: C14.1, R16.1, R40.1, U4.8 (SEL0), U4.9 (SEL1), U4.27 (VDDI)
VREF: C35.1, R29.2, R30.1, TP7.1, U8.3 (+), U8.5 (+)

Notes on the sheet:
AKA Test 1
buffer
Bias generator
Electrolytic, fairly large, feeding into buffer
AKA Test0
Volume control, ratio of the two Rs connected to Pin 6 changes the volume gain

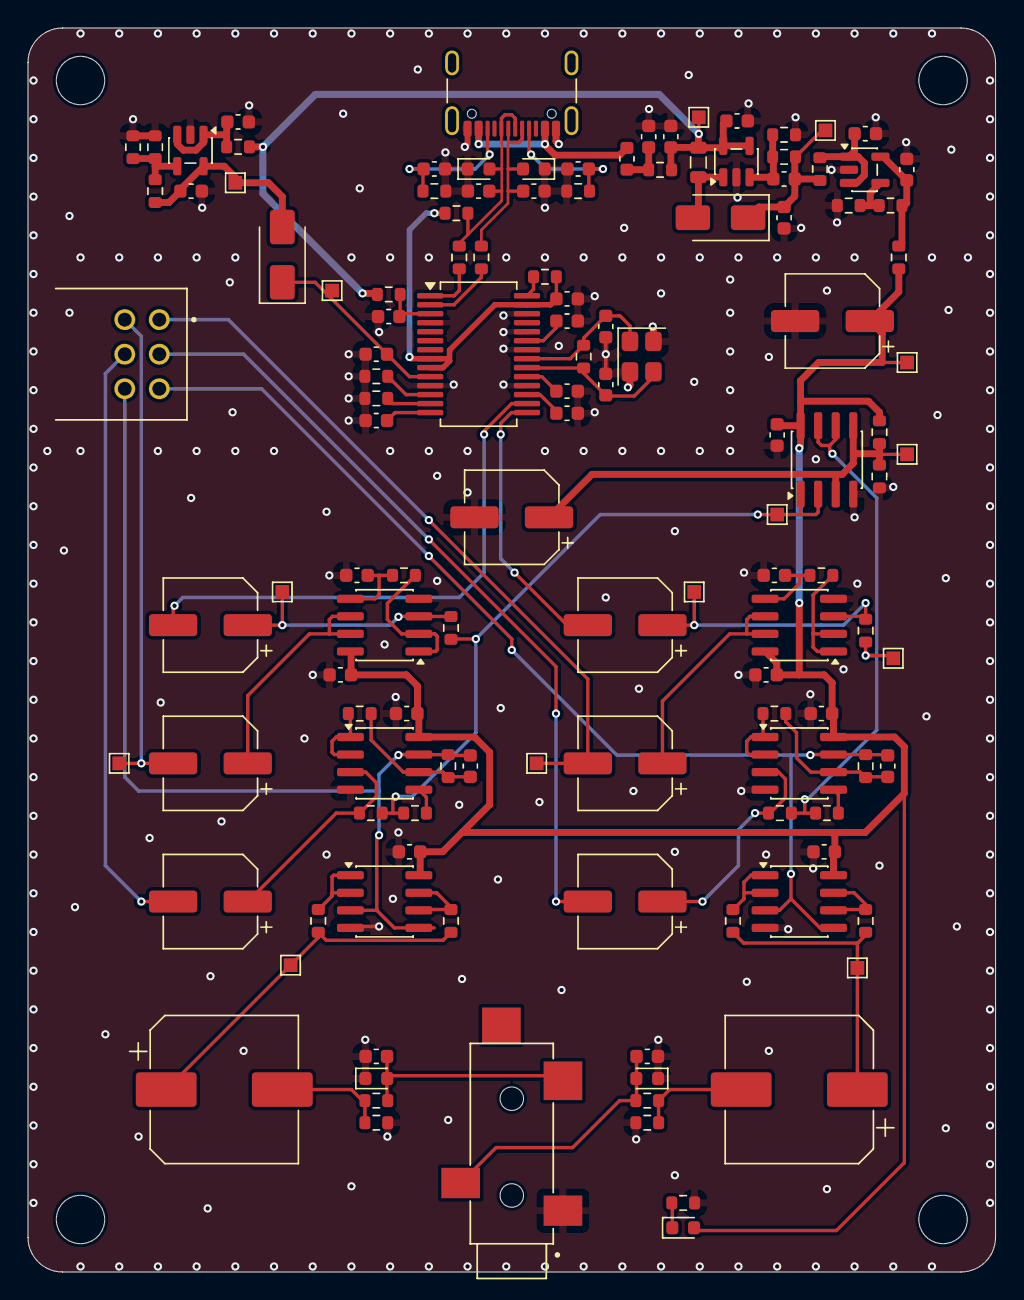
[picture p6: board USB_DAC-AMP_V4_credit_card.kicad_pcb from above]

Board: 4 copper layers, 70.0 x 90.0 mm, 131 parts (0 on the bottom side), 70 nets.

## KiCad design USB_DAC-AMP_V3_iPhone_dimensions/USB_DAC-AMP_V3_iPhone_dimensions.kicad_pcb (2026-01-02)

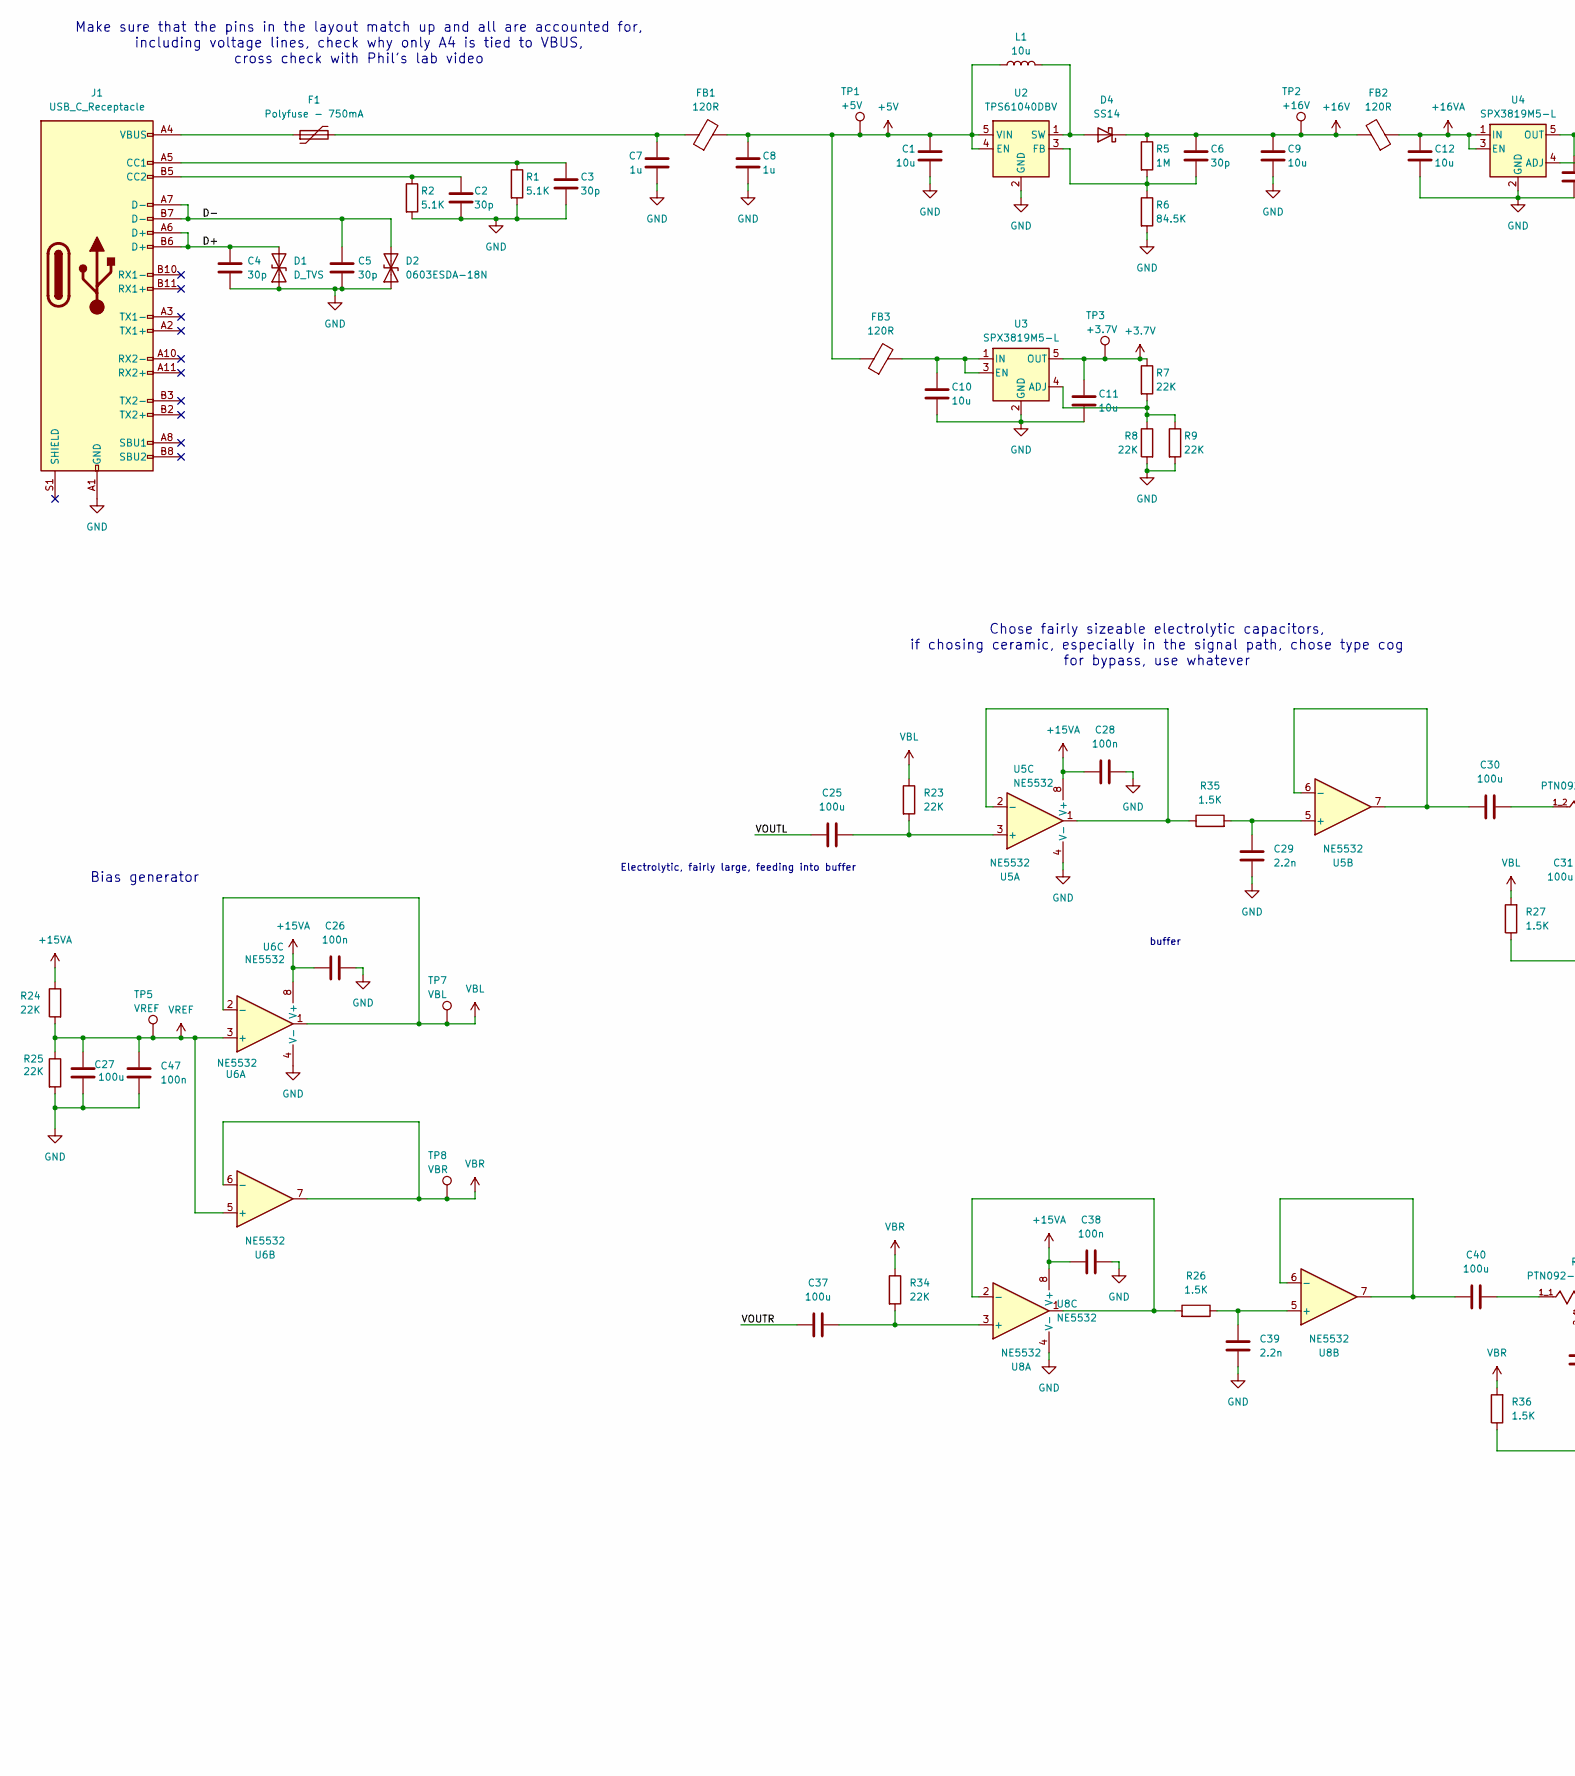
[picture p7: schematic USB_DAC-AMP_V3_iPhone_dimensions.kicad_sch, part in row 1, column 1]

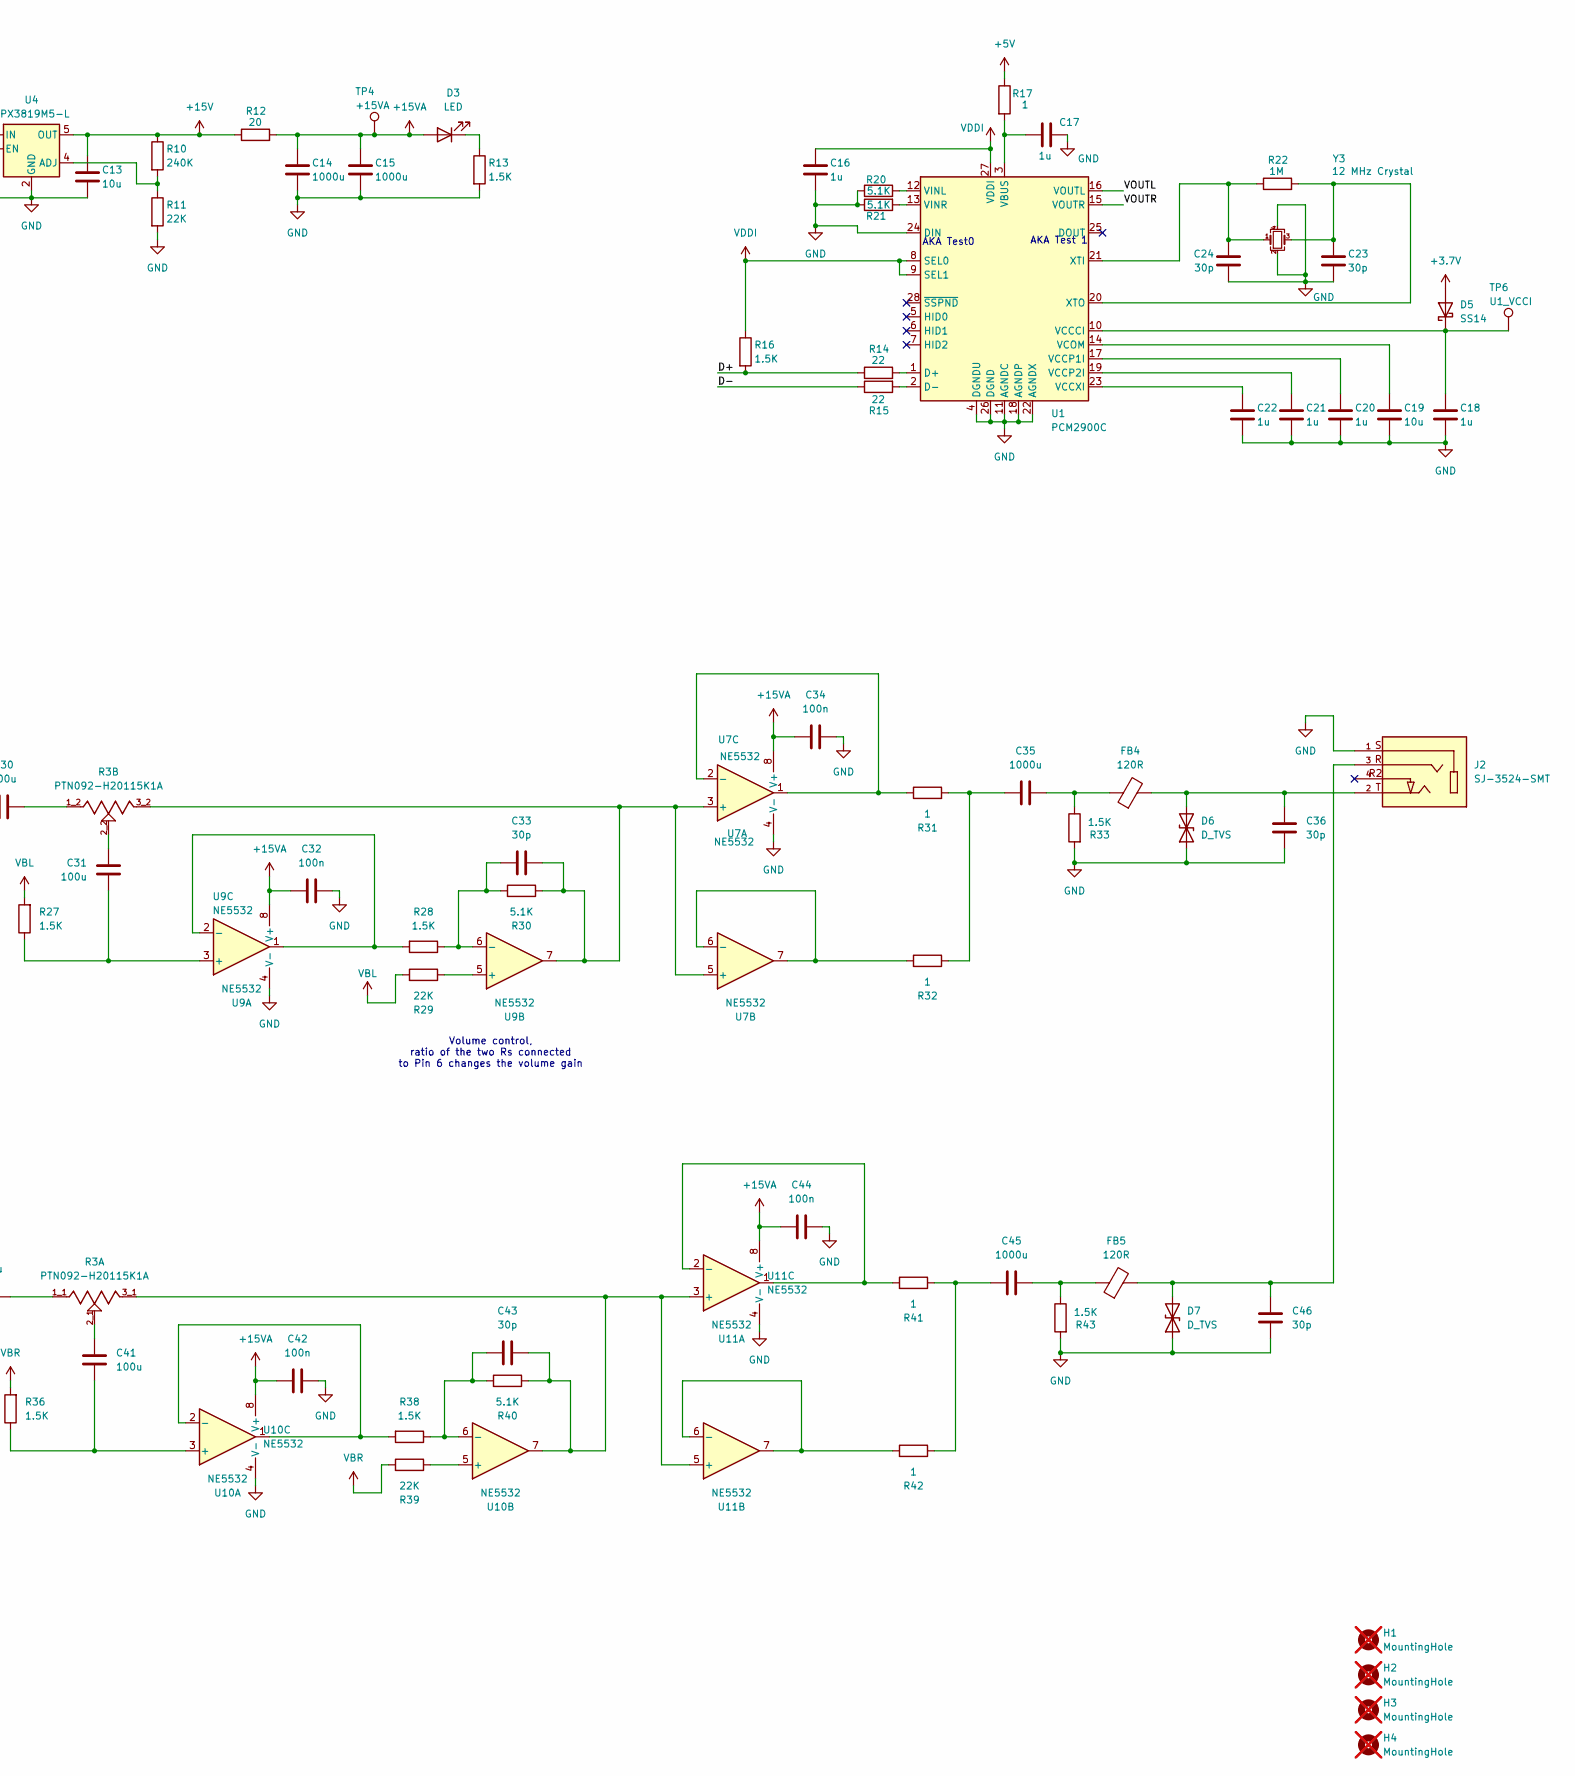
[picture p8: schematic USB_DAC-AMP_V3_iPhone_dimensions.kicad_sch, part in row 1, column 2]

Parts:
C1, C9, C10, C11, C12, C13, C19: 10u; C_0603_1608Metric_Pad1.08x0.95mm_HandSolder; LCSC C1035
C2, C3, C4, C5, C6, C23, C24, C33, C36, C43, C46: 30p; C_0603_1608Metric_Pad1.08x0.95mm_HandSolder; LCSC C1658
C7, C8, C16, C17, C18, C20, C21, C22: 1u; C_0603_1608Metric_Pad1.08x0.95mm_HandSolder; LCSC C1592
C14, C15, C35, C45: 1000u; CP_EIA-7343-43_Kemet-X_HandSolder; LCSC C696799
C25, C27, C30, C31, C40, C41: 100u; CP_EIA-7343-43_Kemet-X_HandSolder; LCSC C132558
C26, C28, C32, C34, C38, C42, C44, C47: 100n; C_0603_1608Metric_Pad1.08x0.95mm_HandSolder; LCSC C1590
C29, C39: 2.2n; C_0603_1608Metric_Pad1.08x0.95mm_HandSolder; LCSC C1028
C37: 100u; CP_EIA-7343-15_Kemet-W; LCSC C1002
D1, D6, D7: D_TVS; D_0603_1608Metric_Pad1.05x0.95mm_HandSolder
D2: 0603ESDA-18N; D_0603_1608Metric_Pad1.05x0.95mm_HandSolder
D3: LED; LED_0603_1608Metric_Pad1.05x0.95mm_HandSolder
D4, D5: SS14; D_SMA
F1: Polyfuse - 750mA; Fuse_0603_1608Metric_Pad1.05x0.95mm_HandSolder
FB1, FB2, FB3, FB4, FB5: 120R; R_0603_1608Metric_Pad0.98x0.95mm_HandSolder
H1, H2, H3, H4: MountingHole; MountingHole_3.5mm; not fitted
J1: USB_C_Receptacle; USB_C_Receptacle_GCT_USB4105-xx-A_16P_TopMnt_Horizontal
J2: SJ-3524-SMT; PARTREV 1.03; DigiKey_Part_Number CP-3524SJCT-ND
L1: 10u; L_0805_2012Metric_Pad1.05x1.20mm_HandSolder
R1, R2, R20, R21, R30, R40: 5.1K; R_0603_1608Metric_Pad0.98x0.95mm_HandSolder
R3: PTN092-H20115K1A; TRIM_PTN092-H20115K1A; PARTREV 1.01; DigiKey_Part_Number 2223-PTN092-H20115K1A-ND
R5, R22: 1M; R_0603_1608Metric_Pad0.98x0.95mm_HandSolder
R6: 84.5K; R_0603_1608Metric_Pad0.98x0.95mm_HandSolder
R7, R8, R9, R11, R23, R24, R25, R29, R34, R39: 22K; R_0603_1608Metric_Pad0.98x0.95mm_HandSolder
R10: 240K; R_0603_1608Metric_Pad0.98x0.95mm_HandSolder
R12: 20; R_0603_1608Metric_Pad0.98x0.95mm_HandSolder
R13, R16, R26, R27, R28, R33, R35, R36, R38, R43: 1.5K; R_0603_1608Metric_Pad0.98x0.95mm_HandSolder
R14, R15: 22; R_0603_1608Metric_Pad0.98x0.95mm_HandSolder
R17, R31, R32, R41, R42: 1; R_0603_1608Metric_Pad0.98x0.95mm_HandSolder
TP1: +5V; TestPoint_Pad_1.0x1.0mm
TP2: +16V; TestPoint_Pad_1.0x1.0mm
TP3: +3.7V; TestPoint_Pad_1.0x1.0mm
TP4: +15VA; TestPoint_Pad_1.0x1.0mm
TP5: VREF; TestPoint_Pad_1.0x1.0mm
TP6: U1_VCCI; TestPoint_Pad_1.0x1.0mm
TP7: VBL; TestPoint_Pad_1.0x1.0mm
TP8: VBR; TestPoint_Pad_1.0x1.0mm
U1: PCM2900C; SSOP-28_5.3x10.2mm_P0.65mm
U2: TPS61040DBV; SOT-23-5
U3, U4: SPX3819M5-L; SOT-23-5
U5, U6, U7, U8, U9, U10, U11: NE5532; SOIC-8_5.3x5.3mm_P1.27mm
Y3: 12 MHz Crystal; Crystal_SMD_3225-4Pin_3.2x2.5mm

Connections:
+3.7V: C11.1, D5.2 (A), R7.1, TP3.1, U3.5 (OUT)
+5V: C1.1, C8.1, FB1.2, FB3.1, L1.1, R17.1, TP1.1, U2.4 (EN), U2.5 (VIN)
+15V: C13.1, R10.1, R12.1, U4.5 (OUT)
+15VA: C14.1, C15.1, C26.1, C28.1, C32.1, C34.1, C38.1, C42.1, C44.1, D3.2 (A), R12.2, R24.1, TP4.1, U5.8 (V+), U6.8 (V+), U7.8 (V+), U8.8 (V+), U9.8 (V+), U10.8 (V+), U11.8 (V+)
+16V: C6.1, C9.1, D4.1 (K), FB2.2, R5.1, TP2.1
+16VA: C12.1, FB2.1, U4.1 (IN), U4.3 (EN)
/D+: C4.1, D1.2 (A2), J1.A6 (D+), J1.B6 (D+), R14.1, R16.2; also elsewhere on the board
/D-: C5.1, D2.2 (A2), J1.A7 (D-), J1.B7 (D-), R15.1; also elsewhere on the board
/VOUTL: C25.1, U1.16 (VOUTL)
/VOUTR: C37.1, U1.15 (VOUTR)
GND: C1.2, C2.2, C3.2, C4.2, C5.2, C7.2, C8.2, C9.2, C10.2, C11.2, C12.2, C13.2, C14.2, C15.2, C16.2, C17.2, C18.2, C19.2, C20.2, C21.2, C22.2, C23.2, C24.2, C26.2, C27.1, C28.2, C29.1, C32.2, C34.2, C36.1, C38.2, C39.1, C42.2, C44.2, C46.1, C47.1, D1.1 (A1), D2.1 (A1), D6.1 (A1), D7.1 (A1), J1.A1 (GND), J1.A12 (GND), J1.B1 (GND), J1.B12 (GND), J2.1, R1.2, R2.2, R6.2, R8.2, R9.2, R11.2, R13.2, R20.1, R21.1, R25.2, R33.2, R43.2, U1.4 (DGNDU), U1.11 (AGNDC), U1.18 (AGNDP), U1.22 (AGNDX), U1.24 (DIN), U1.26 (DGND), U2.2 (GND), U3.2 (GND), U4.2 (GND), U5.4 (V-), U6.4 (V-), U7.4 (V-), U8.4 (V-), U9.4 (V-), U10.4 (V-), U11.4 (V-), Y3.2, Y3.4; also elsewhere on the board
unnamed: C7.1, F1.2, FB1.1
unnamed: C30.2, R3.1_2
unnamed: C31.2, R3.2_2
unnamed: C35.1, R31.2, R32.1
unnamed: C35.2, FB4.1, R33.1
unnamed: C40.2, R3.1_1
unnamed: C41.2, R3.2_1, R21.1_1
unnamed: C45.1, R41.1, R42.1
unnamed: C45.2, FB5.1, R43.1
unnamed: D3.1 (K), R13.1
unnamed: D4.2 (A), L1.2, U2.1 (SW)
unnamed: C18.1, D5.1 (K), TP6.1, U1.10 (VCCCI)
unnamed 26: C36.2, D6.2 (A2), FB4.2, J2.2; also elsewhere on the board
unnamed 27: C46.2, D7.2 (A2), FB5.2, J2.3; also elsewhere on the board
unnamed 28: F1.1, J1.A4 (VBUS), J1.A9 (VBUS), J1.B4 (VBUS), J1.B9 (VBUS); also elsewhere on the board
unnamed 29: C3.1, J1.A5 (CC1), R1.1; also elsewhere on the board
unnamed 30: C2.1, J1.B5 (CC2), R2.1; also elsewhere on the board
unnamed: R14.2, U1.1 (D+)
unnamed: R15.2, U1.2 (D-)
unnamed: C17.1, R17.2, U1.3 (VBUS)
unnamed: C20.1, U1.17 (VCCP1I)
unnamed: C21.1, U1.19 (VCCP2I)
unnamed: C22.1, U1.23 (VCCXI)
unnamed: C19.1, U1.14 (VCOM)
unnamed: R20.2, U1.12 (VINL)
unnamed 39: R21.2, U1.13 (VINR); also elsewhere on the board
unnamed: C24.1, R22.1, U1.21 (XTI), Y3.1
unnamed: C23.1, R22.2, U1.20 (XTO), Y3.3
unnamed: C6.2, R5.2, R6.1, U2.3 (FB)
unnamed: R7.2, R8.1, R9.1, U3.4 (ADJ)
unnamed: C10.1, FB3.2, U3.1 (IN), U3.3 (EN)
unnamed: R10.2, R11.1, U4.4 (ADJ)
unnamed: C25.2, R21.3_2, R23.2, U5.3 (+)
unnamed: R35.1, U5.1, U5.2 (-)
unnamed: C29.2, R35.2, U5.5 (+)
unnamed: C30.1, U5.6 (-), U5.7
unnamed: C33.2, R3.3_2, R30.1, U7.3 (+), U7.5 (+), U9.7
unnamed: R31.1, U7.1, U7.2 (-)
unnamed: R32.2, U7.6 (-), U7.7
unnamed: C37.2, R34.2, U8.3 (+)
unnamed: R26.2, U8.1, U8.2 (-)
unnamed: C39.2, R26.1, U8.5 (+)
unnamed: C40.1, U8.6 (-), U8.7
unnamed: C31.1, R21.3_1, R27.1, U9.3 (+)
unnamed: R28.2, U9.1, U9.2 (-)
unnamed: R29.1, U9.5 (+)
unnamed: C33.1, R28.1, R30.2, U9.6 (-)
unnamed: C41.1, R36.1, U10.3 (+)
unnamed: R38.2, U10.1, U10.2 (-)
unnamed: R39.1, U10.5 (+)
unnamed: C43.1, R38.1, R40.2, U10.6 (-)
unnamed: C43.2, R3.3_1, R40.1, U10.7, U11.3 (+), U11.5 (+)
unnamed: R41.2, U11.1, U11.2 (-)
unnamed: R42.2, U11.6 (-), U11.7
VBL: R23.1, R27.2, R29.2, TP7.1, U6.1, U6.2 (-)
VBR: R34.1, R36.2, R39.2, TP8.1, U6.6 (-), U6.7
VDDI: C16.1, R16.1, U1.8 (SEL0), U1.9 (SEL1), U1.27 (VDDI)
VREF: C27.2, C47.2, R24.2, R25.1, TP5.1, U6.3 (+), U6.5 (+)

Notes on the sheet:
Chose fairly sizeable electrolytic capacitors, if chosing ceramic, especially in the signal path, chose type cog for bypass, use whatever
AKA Test 1
buffer
Bias generator
Electrolytic, fairly large, feeding into buffer
Make sure that the pins in the layout match up and all are accounted for, including voltage lines, check why only A4 is tied to VBUS, cross check with Phil's lab video
AKA Test0
Volume control, ratio of the two Rs connected to Pin 6 changes the volume gain

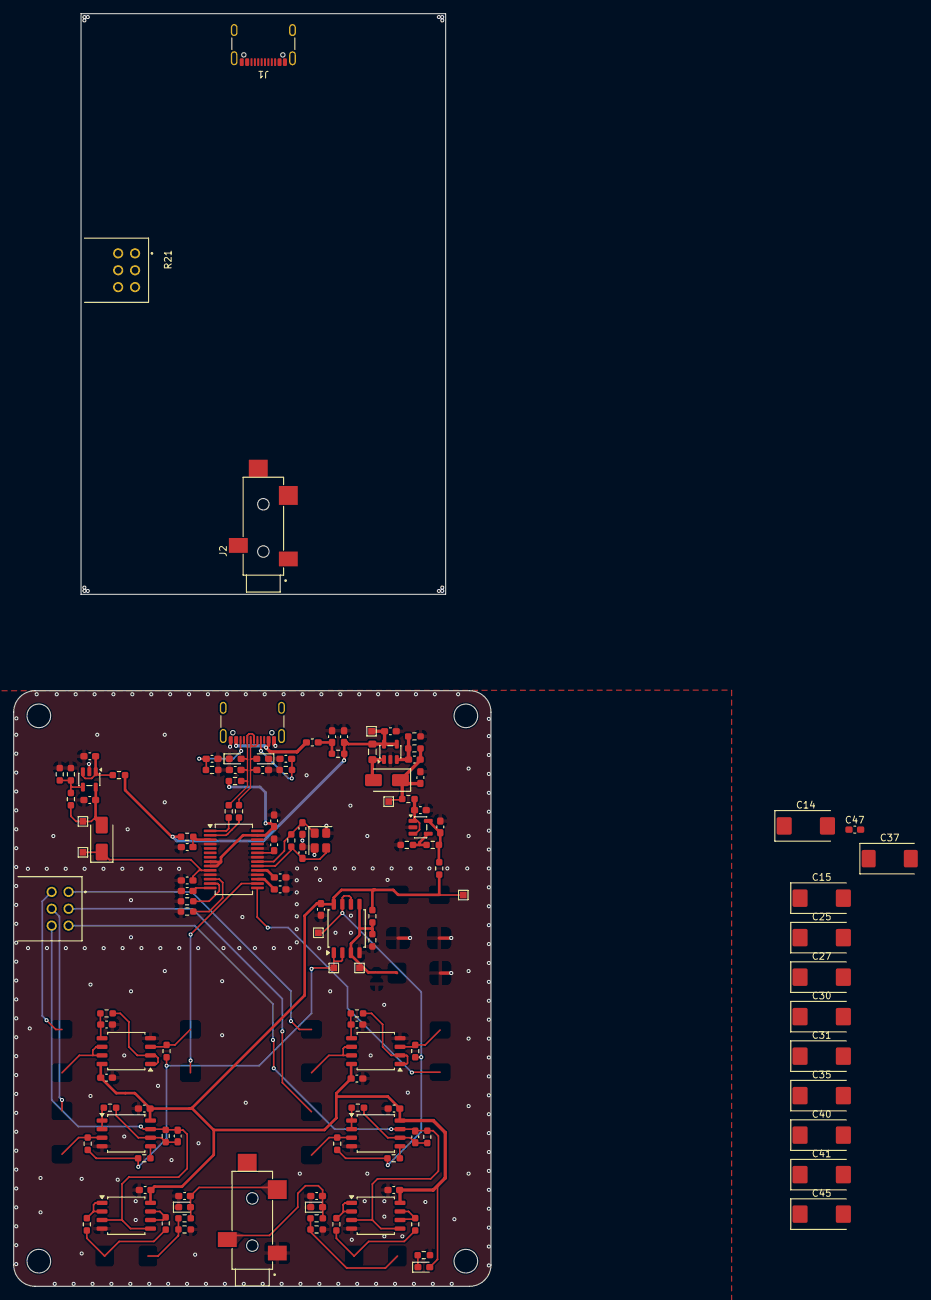
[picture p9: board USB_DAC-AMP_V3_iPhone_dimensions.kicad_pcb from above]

Board: 4 copper layers, 70.7 x 88.2 mm, 129 parts (0 on the bottom side), 69 nets.

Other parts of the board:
J1#2: USB_C_Receptacle; USB_C_Receptacle_GCT_USB4105-xx-A_16P_TopMnt_Horizontal
J2#2: SJ-3524-SMT
R21#2: 1.5k; R_0603_1608Metric_Pad0.98x0.95mm_HandSolder

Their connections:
/D+: J1#2.A6 (D+), J1#2.B6 (D+); also elsewhere on the board
/D-: J1#2.A7 (D-), J1#2.B7 (D-); also elsewhere on the board
GND: J1#2.A1 (GND), J1#2.A12 (GND), J1#2.B1 (GND), J1#2.B12 (GND), J2#2.1, R21#2.1; also elsewhere on the board
unnamed 26: J2#2.2; also elsewhere on the board
unnamed 27: J2#2.3; also elsewhere on the board
unnamed 28: J1#2.A4 (VBUS), J1#2.A9 (VBUS), J1#2.B4 (VBUS), J1#2.B9 (VBUS); also elsewhere on the board
unnamed 29: J1#2.A5 (CC1); also elsewhere on the board
unnamed 30: J1#2.B5 (CC2); also elsewhere on the board
unnamed 39: R21#2.2; also elsewhere on the board

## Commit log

2025-12-24 Schematic USB and IC design mostly complete
    [USB_DAC-AMP.kicad_pcb, USB_DAC-AMP.kicad_sch]
2025-12-27 finished USB_DAC-AMP schematic
    [USB_DAC-AMP_WITH_TONE_CTRL.kicad_pcb, USB_DAC-AMP_WITH_TONE_CTRL.kicad_sch]
2025-12-27 finished V1 footprint assignments
    [USB_DAC-AMP.kicad_pcb, USB_DAC-AMP.kicad_sch]
2025-12-30 created V4 to change board dimensions, update schematic
    changed out caps to be electrolytic
    board dimensions are now whole numbers
    [USB_DAC-AMP_V2_different_layout.kicad_pcb, USB_DAC-AMP_V2_different_layout.kicad_sch, USB_DAC-AMP_V3_iPhone_dimensions.csv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]
2025-12-31 updated V4
    [USB_DAC-AMP_V3_iPhone_dimensions.kicad_pcb, USB_DAC-AMP_V4_credit_card.kicad_pcb, USB_DAC-AMP_V4_credit_card.kicad_sch]
2026-01-02 Finished V4 layout
    [USB_DAC-AMP_V4_credit_card.kicad_pcb, USB_DAC-AMP_V4_credit_card.kicad_sch]
2026-01-04 Submitted V1 to Kicad
    [USB_DAC-AMP_V3_iPhone_dimensions.kicad_pcb, USB_DAC-AMP_V4_credit_card.csv, USB_DAC-AMP_V4_credit_card.kicad_pcb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]
2026-01-12 misc files upload
    [USB_DAC-AMP_V4_credit_card.kicad_pcb]
